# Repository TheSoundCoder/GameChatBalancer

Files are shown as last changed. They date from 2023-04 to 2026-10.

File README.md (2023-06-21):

# GameChatBalancer
GameChatBalancer is an **opensource hardware audio balancer** for Windows PCs. The functionality is inspired by the Chatmix / Gamevoice mix function of some available headsets.

GameChatBalancer lets you use an Arduino (or compatible) based knob or slider to **balance the volume of chat-software and games** so that you can **easily
tune the audio volume while playing** without any interruption by just turning a knob or moving a slider.

The project consists of two components. A small **systray application** for your PC and an Arduino based **cheap to build** hardware.

# Table of contents
- [Features](https://github.com/TheSoundCoder/GameChatBalancer#Features)
- [Build Hardware](https://github.com/TheSoundCoder/GameChatBalancer#build-hardware)
  - [Schematic](https://github.com/TheSoundCoder/GameChatBalancer#schematic)
  - [Material](https://github.com/TheSoundCoder/GameChatBalancer#material)
  - [Housing](https://github.com/TheSoundCoder/GameChatBalancer#housing)
- [Make your own GameChatBalancer](https://github.com/TheSoundCoder/GameChatBalancer#make-your-own-gamechatbalancer)
- [Licences](https://github.com/TheSoundCoder/GameChatBalancer#licences)
- [Roadmap](https://github.com/TheSoundCoder/GameChatBalancer#roadmap)
- [Special Thanks](https://github.com/TheSoundCoder/GameChatBalancer#special-thanks)
- [Help & Feedback](https://github.com/TheSoundCoder/GameChatBalancer/#help--feedback-wanted)

# Features
1. Hardware
   - Only sends data via the serial port if the chose volume level changed -> **no permanent datastream**
   - **Noise reduction** in case you are using cheap components - especially the potentiometer
     - Levels: Off, Low, Medium, High (default)
     - Adjustable at runtime via Systray Application

2. Systray Application
   - Easy configuration via GUI - Assign applications via **drag and drop**
   - Assign **multiple applications** to the "Game" and "Chat" category
   - **Auto-detect** the Arduino based hardware
   - The application detects when the hardware is removed and will automatically reconnect when plugged in again (**USB event based**)
   - User settings are stored automatically and restored during application startup
   - Invert the values received by the hardware in case your wiring is mixed up

See the application in action:

https://user-images.githubusercontent.com/130736237/235218694-252510ab-6273-4d05-bc87-e7d56919cefa.mp4

This is how it look like in the Windows Audio mixer:

https://user-images.githubusercontent.com/130736237/235218894-d49eed7c-69e4-4d56-9448-dae65230d700.mp4

# Build Hardware
Everything you need to build your own GameChatBalancer ist listed in the [Pricing indication](https://github.com/TheSoundCoder/AudioControl#pricing-indication).
- The potentiometer is connected to an analog pin of your Arduino (or compatible) board. It is powered from the board's 5V (or 3.3V for a Seeed board) output (see schematic)
  - GND = black
  - 5V / 3.3V = red
  - Signal = green
- The board is conected via an USB cable to the PC. **Make sure to check what kind of USB cable is needed for your board.**
- As listed in the Pricing indication I used a **Seeed Xiao SAMD21 Cortex M0+** instead of an Arduino. It comes cheap (5,60€), has a lot of analog connectors and a very small footprint (20mm x 17,5mm x 3,5mm) so that it fits into a small housing. Last but not least it has a USB-C connector.
 
## Schematic
In the schematic below, you can find two options:
1. *Left* is the setup with the *Seeed Xiao SAMD21 Cortex M0+*. **Ensure to connect the potentiometer to the 3.3V output** of the board as the 5V will probably kill the board's microcontroller.
2. *Right* is the setup with an *Arduino*.

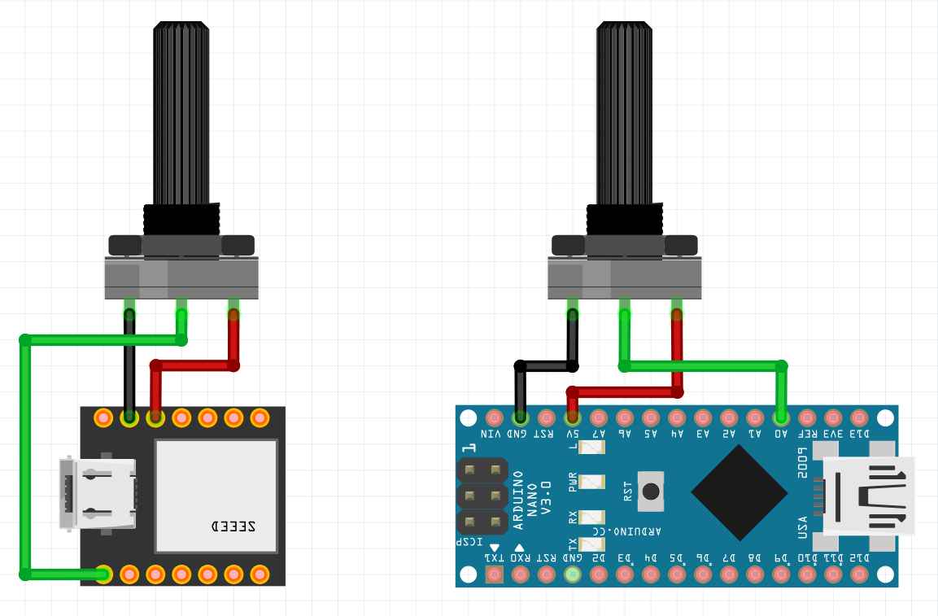
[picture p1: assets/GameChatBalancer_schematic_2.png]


## Material
**Please keep in mind that a cheap potentiometer can cause noise**, so that noise reduction needs to be switched on in the Systray application.
I use a ~ 3€ poti with a **low tolerance of +-5%** in my device and noise reduction switched off. Cheap potentiometers usually have a tolerance of +-20%.

**Important**: make sure to buy a **linear** potentiometer, not a logarithmic one! 

Item | Price (€)|Link
-----|------|-------
Microcontroller: Seeed Xiao SAMD21 Cortex M0+|5,60|https://www.berrybase.de/en/seeeduino-xiao-arduino-microcontroller-samd21-cortex-m0
Potentiometer Noname 10k (tolerance: +-20%)|0,45|https://www.berrybase.de/en/drehpotentiometer-10k-937-liegend-mono-6mm-loetoesen?c=164
*Optional:* Potentiometer Alpha RV16AF20KB10KM (tolerance: +-5%)|2,99|https://www.conrad.de/de/p/alpha-rv16af20kb10km-dreh-potentiometer-mono-200-mw-10-k-1-st-1694304.html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 
Knob|0,65|https://www.berrybase.de/en/drehknopf-fuer-geraendelte-6-0mm-achse-mit-anzeige-16x16mm-schwarz/grau?c=164
Copper wire isolated|1,50|https://www.berrybase.de/en/kupferschaltdraht-isoliert-oe0-5mm-10m
**Total**|**8,20 - 10,74**|

If you use the listed microcontroller you will additionally need a **USB-C cable**.

## Housing
You can use anything as a housing for your GameChatBalancer - even a matchbox if you do not have a 3D-Printer.

I decided to design and 3D-print one by myself. If you like the "design" you can download either the STL files or GCODE files [here](https://github.com/TheSoundCoder/AudioControl/tree/master/assets/3d-model).

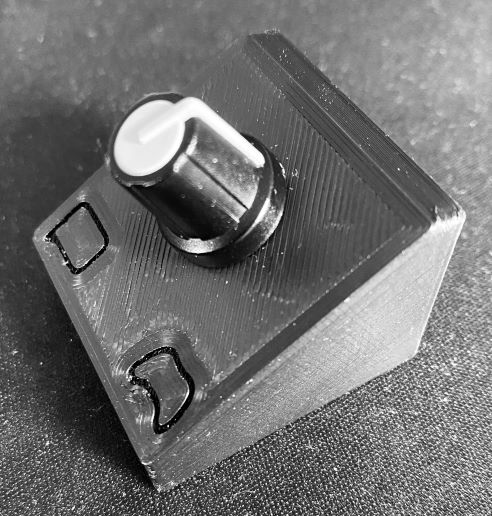
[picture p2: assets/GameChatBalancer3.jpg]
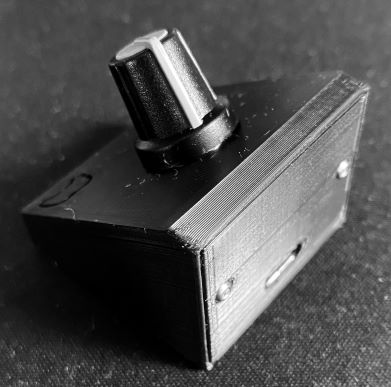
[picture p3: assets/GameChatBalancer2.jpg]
 

# Make your own GameChatBalancer

If you want to build your own GameChatBalancer or get details on how to handle the systray application. Please have a look at the dedicated [manual](https://github.com/TheSoundCoder/GameChatBalancer/blob/master/Manual.md).

# Licences
Icons used under [Creativecommons Attribution 4.0](https://creativecommons.org/licenses/by/4.0/legalcode) from https://icon-icons.com:
Designer | Iconpack | Icon Name | Image
---------|----------|---------|---------
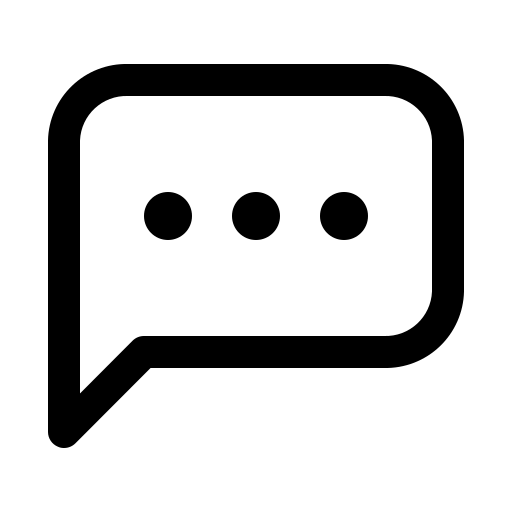
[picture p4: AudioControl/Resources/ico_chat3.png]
Perpixel | Mobile Basic Vol. 1 | conversation Icon | 
Iconicons | Icons - line | Game, controller icon | 
CoreUI | CoreUI Free | Equalizer Icon | 
Steve Shoger | Zondicons | Bug Icon | 
Yannick | General Icons | Refresh Icon | 

# Roadmap
Depending on my free time I would like to make the complete setup flexible so that additional potentiometers are supported. Those could be used to (e.g.):
- Control the master volume of your PC
- Assign single or multiple applications to a potentiometer

I am currently thinking of how the Systray UI and configuration of the Arduino can be done flexible so that no new sketch needs to be uploaded if the overall configuration changes.

# Special Thanks
I would like to thank **@sverrirs for his Gist AudioManager.cs** which accelerated the development and for sure saved me from some pain during the development. I used and modified AudioManager.cs to my needs so that GameChatBalancer is able to adjust the volume of more than one application by application name in one single call.

# Help & Feedback wanted
I created a first issue where help would be very welcome. Maybe it is not an easy one, but if somebody has a good idea or would like to contribute to it, this would be very welcome. This is my first (public) repo, so please be patient with me.

Feedback is also more than welcome. Please let me know if you (dis-) LIKE something or if you see issues in the code have good hints how to improve.

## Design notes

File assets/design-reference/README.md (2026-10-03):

# Design Reference Asset

Lege hier das bereitgestellte Referenzbild ab:

- `GameChatBalancer-Reference.jpeg`

Dieser Asset-Pfad wird in den Projekt-Instructions verwendet und dient als visuelle Leitlinie für die WPF-UI-Modernisierung.

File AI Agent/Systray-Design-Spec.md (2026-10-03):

# GameChatBalancer – Mini-Design-Spec Systray-Popup (WPF, Fluent)

## Ziel
Systray-Popup visuell an die neue WPF-Hauptoberfläche angleichen (Windows-11-/Fluent-inspiriert), mit zwei klaren Zuständen:
1. **Arduino verbunden** (Hardware-Steuerung aktiv)
2. **Arduino nicht verbunden** (Software-Steuerung aktiv)

Die Mockups sind Leitlinie, keine pixelgenaue Vorgabe. Funktionalität/Stabilität haben Vorrang.

---

## 1) Layout & Größe
- Popup als kompakte Card über der Taskleiste.
- Zielgröße (Startwert): ca. **360–400px Breite**, Höhe dynamisch nach Inhalt.
- Außenabstand: 8–12px zur Taskleistenkante.
- Innenabstand Card: 16px.
- Vertikaler Rhythmus: 8/12px zwischen Gruppen.

### Struktur (von oben nach unten)
1. **Header**
   - App-Icon + Titel "GameChatBalancer"
2. **Status-Card**
   - Dot + Statuszeile + optionale Geräteinfo
3. **Balance-Bereich**
   - Game/Chat Werte + Gradient-Track + Indikator
4. **Mode-spezifischer Block**
   - Connected: Noise Reduction + Invert
   - Disconnected: Software-Control-Hinweis + Hotkeys
5. **Actions-Liste**
   - Open App
   - Start with Windows (Toggle)
   - Exit

---

## 2) Farb- & Materialsystem
(auf Basis `AI Agent/UI-Design-Reference.md`)

- Background/Base: `#0A1326`
- Surface 1: `#10203A`
- Surface 2: `#132743`
- Border/Subtle: `#2A3D5A`
- Text Primary: `#F2F6FF`
- Text Secondary: `#AFC0D8`
- Accent Game: `#2B8CFF`
- Accent Chat: `#8A5CFF`
- Success (Connected): `#22C55E`
- Error (Disconnected): `#EF4444`

Material:
- Hauptpanel: Surface 2
- Eingelassene Bereiche/Rows: Surface 1
- Border 1px subtil
- Keine harten Glows, nur sanfte Kontraste

---

## 3) Typografie
- Font: Segoe UI Variable / Segoe UI
- Größen:
  - Titel: 30
  - Abschnittstitel: 16
  - Primärtext: 14
  - Sekundärtext/Meta: 12–13
- Gewicht:
  - Titel/Sektion: Semibold/Bold
  - Meta: Regular

---

## 4) Corner Radius, Spacing, Controls
- Große Card: 12px
- Kleine Unterkarten/Rows: 8–10px
- Toggle-Stil identisch zum WPF-Hauptfenster (`HardwareToggleStyle`)
- Dropdown-Stil für Noise Reduction an Hauptfenster angleichen
- Fokuszustände sichtbar, Hover klar, Disabled lesbar

---

## 5) Zustand A – Arduino verbunden
- Statuszeile:
  - Grüner Dot + „Arduino verbunden“
  - Unterzeile optional: Gerät + Firmware
- Hardware-Steuerung sichtbar:
  - Noise Reduction (Value + Auswahl)
  - Invert Control (Toggle)
- Software-Control-Hinweis **ausgeblendet**

## 6) Zustand B – Arduino nicht verbunden
- Statuszeile:
  - Roter Dot + „Kein Arduino verbunden“
  - Unterzeile: „Software-Steuerung aktiv“
- Hardware-Steuerung **ausgeblendet**:
  - Kein Noise Reduction Block
  - Kein Invert Toggle
- Software-Control-Info sichtbar:
  - Hinweistext zu 5%-Schritten
  - Hotkeys:
	- Ctrl + Shift + ← / →
	- Ctrl + Shift + ↓ (Center 50)

---

## 7) Interaktion
- Open App: öffnet Hauptfenster
- Start with Windows: synchron mit bestehender Autostart-Logik
- Exit: beendet App sauber
- Klick außerhalb Popup: schließt Popup (wie Kontext-ähnliches Flyout)

---

## 8) Accessibility & UX
- Tastaturfokus für alle aktiven Elemente
- Nicht nur Farbe als Statussignal (Text immer vorhanden)
- Kontrast min. AA-nah für Primärtexte
- Tooltips für Status/unklare Icons

---

## 9) Technische Leitplanken für Umsetzung
- Schrittweise umsetzen:
  1. Nur Popup-Layout + Styles
  2. State-Switch Connected/Disconnected
  3. Actions/Bindings
- Bestehende Services/Logik zuerst weiterverwenden, keine Big-Bang-Refactorings.
- Nach jedem Schritt: Build + kurzer Smoke-Test.

---

## 10) Abnahmekriterien (Systray-Phase)
- Popup folgt visuell der WPF-Designsprache.
- Connected/Disconnected unterscheiden sich klar und korrekt.
- Bei Disconnected sind Hardware-Controls vollständig ausgeblendet.
- Software-Control-Hotkeys sind im Popup sichtbar dokumentiert.
- Actions (Open App, Start with Windows, Exit) funktionieren wie bisher.
- Keine Regression bei Tray-Show/Hide/Exit.

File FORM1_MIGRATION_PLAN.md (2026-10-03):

# FORM1 Migration Plan

## Scope (Phase 1 only)
This document captures the current Form1 dependency graph and a safe migration path.  
No Form1 deletion is performed in this phase.

---

## 1) Current responsibilities of `Form1`

### Application host / lifecycle
- App startup host (`Program.Main` starts `new Form1()`)
- Subscribes global lifecycle events:
  - `Application.ApplicationExit`
  - `SystemEvents.SessionEnding`
- Owns startup sequencing (`Form1_Load`), including initialization order.
- Owns shutdown sequencing (`OnApplicationExit`, `PersistSettingsImmediate`, service stop/shutdown).

### Tray behavior
- Owns `NotifyIcon` and interaction entry points (`trayicon_MouseUp`).
- Creates/displays `SystrayPopupWindow` and positions it.
- Handles tray commands (`Show`/`Exit`) via `openToolStripMenuItem_Click` and `closeToolStripMenuItem_Click`.

### WPF window hosting/orchestration
- Creates `MainWindow` with many callbacks/providers.
- Keeps `MainWindow` and systray popup synchronized with runtime state.
- Intercepts WPF main-window close (`WpfMainWindow_Closing`) to hide instead of exit.

### Audio control orchestration
- Calls `IAudioBalanceService.ApplyBalance(...)`.
- Maintains current balance mirror in WinForms controls (`trackBar1`, labels) and propagates to WPF UI.
- Responds to incoming Arduino volume values via `controlVolume(...)`.

### Arduino/serial orchestration
- Uses `ISerialDeviceService` and reacts to `ConnectionStatusChanged`.
- Triggers startup handshake/value fetch (`GetVol`) and noise reduction command send.
- Applies noise reduction/invert settings and propagates to UI surfaces.

### Process/audio-session detection orchestration
- Uses `IAudioSessionService`.
- Subscribes to `AudioSessionsChanged` and refreshes assignment lists/snapshots.

### Settings and assignment persistence orchestration
- Reads/writes `ISettingsStore`.
- Maintains `GAME`/`CHAT` assignment strings and app path mapping.
- Persists state at runtime and on shutdown.

### Hotkeys (software control when Arduino disconnected)
- Registers/unregisters Win32 hotkeys in host window (`WndProc`).
- Applies step/snap/center logic and routes result through balance apply path.

### Debug/log sink and UI debug state
- Maintains in-memory debug log list.
- Routes logs into legacy WinForms textbox and WPF debug page callbacks.

### Legacy WinForms UI state bridge (technical debt)
- Exposes/uses WinForms control state as runtime state source:
  - COM dropdown
  - invert checkbox
  - volume labels/trackbar
  - listboxes for assignment
- This state is currently used by serial/audio paths indirectly.

---

## 2) All known consumers/dependencies on `Form1`

## Direct references
- `AudioControl/Program.cs`
  - `WinFormsApplication.Run(new Form1())`
- `AudioControl/SerialDeviceService.cs`
  - Constructor signature `SerialDeviceService(Form1 form)`
  - Calls `USBandCOM.HandOverForm(form)`
- `AudioControl/AudioSessionService.cs`
  - Constructor signature `AudioSessionService(Form1 form)`
  - Calls `AudioManager.AudioManager.HandOverForm(form)`
- `AudioControl/USBandCOM.cs`
  - Static field `MainForm` of type `AudioControl.Form1`
  - Extensive calls to `MainForm.*` for logging/UI-thread marshaling/state updates
- `AudioControl/AudioManager.cs`
  - Static field `MainForm` of type `AudioControl.Form1`
  - Uses `MainForm.Debug` + `MainForm.SendToLog(...)`

## Indirect dependencies
- WPF UIs depend on Form1-owned callback graph:
  - `GameChatBalancer.Wpf/MainWindow.xaml.cs` (callbacks provided by Form1)
  - `GameChatBalancer.Wpf/SystrayPopupWindow.xaml.cs` (callbacks provided by Form1)
- USB watcher service (`UsbWatcherService`) and serial layer depend on `USBandCOM`, which currently depends on Form1.

## Startup/lifecycle dependency
- Entire application runtime currently requires Form1 as process host window/message pump anchor.

---

## 3) Responsibility -> proposed destination

| Responsibility in Form1 | Proposed destination |
|---|---|
| App startup orchestration | New `AppHost` / `ApplicationLifecycleService` (non-UI) |
| Tray icon + menu/popup wiring | New `ITrayHostService` (WinForms `NotifyIcon` can remain internal implementation detail) |
| MainWindow creation/show/hide policy | New `IWindowCoordinator` / `IUiCoordinator` |
| Runtime app state (connected, balance, noise, invert, assignments) | New `IAppStateStore` + event stream |
| Software-control hotkeys | New `ISoftwareControlHotkeyService` (host-level, independent of MainWindow) |
| Serial value intake + command dispatch coordination | New `IArduinoController` (uses `ISerialDeviceService`) |
| Balance application orchestration | Keep `IAudioBalanceService`, add thin `IBalanceController` for orchestration/state events |
| Audio-session refresh/reassignment triggering | New `IAssignmentRefreshService` (uses `IAudioSessionService`) |
| Debug logging fan-out | New `IAppLogger` / `IDebugLogStore` abstraction |
| Settings persistence flow | Keep `ISettingsStore`, move shutdown save into lifecycle service |

Guiding rule: no `Form1` reference in core/services; UI consumes abstractions/events.

---

## 4) Required interfaces/services (incremental)

## Reuse existing
- `ISerialDeviceService`
- `IAudioSessionService`
- `IAudioBalanceService`
- `IUsbWatcherService`
- `ISettingsStore`
- `IAutoStartService`

## Introduce (small focused components)
- `IAppStateStore` (current state + change events)
- `IArduinoController` (serial connect/disconnect, incoming value event, NR ack event, send commands)
- `IBalanceController` (apply balance, emit balance changed)
- `ISoftwareControlHotkeyService` (register/unregister, hotkey events)
- `ITrayHostService` (notify icon lifecycle, show/hide popup commands)
- `IUiCoordinator` (open main window, sync UI state, close policy)
- `IAppLifecycleService` (startup/shutdown sequencing and disposal)
- `IDebugLogStore` (log sink + observable log entries)

No “Form1Service” aggregation class.

---

## 5) Required event flows (event-driven, no polling)

## Serial/Arduino flow
1. `IArduinoController.ConnectionStatusChanged`
2. `IAppStateStore` updates connected/port state
3. Subscribers update:
   - Tray popup state
   - MainWindow state
   - Hotkey service registration policy

## Arduino value flow
1. `IArduinoController.ValueReceived(float)`
2. `IBalanceController.ApplyInput(value, invert)`
3. `IBalanceController.BalanceChanged` (display/game/chat)
4. Subscribers:
   - Audio controller/session volume application
   - MainWindow balance UI
   - Systray popup balance UI

## Noise reduction flow
1. UI command -> `IArduinoController.SetNoiseReduction(level)`
2. state enters applying
3. NR confirmation event from serial -> state confirmed
4. timeout/error event -> state error

## Audio session change flow
1. `IAudioSessionService.AudioSessionsChanged`
2. assignment refresh service recomputes available apps
3. `IAppStateStore.AvailableAppsChanged`
4. MainWindow refreshes assignment lists

## Lifecycle flow
- Startup: initialize services in host service order (settings -> serial/usb watcher -> session monitor -> tray)
- Shutdown: reverse order with deterministic dispose/unsubscribe.

---

## 6) Event handlers currently wired through Form1

## Framework/lifecycle
- `Application.ApplicationExit += OnApplicationExit`
- `SystemEvents.SessionEnding += OnSessionEnding`

## Service events
- `serialDeviceService.ConnectionStatusChanged += SerialDeviceService_ConnectionStatusChanged`
- `audioSessionService.AudioSessionsChanged += AudioSessionService_AudioSessionsChanged`

## WinForms UI handlers (Designer)
- Tray: `trayicon_MouseUp`
- Context menu / commands: `openToolStripMenuItem_Click`, `closeToolStripMenuItem_Click`, `Settings_Opening`
- Controls: `ddl_ComPort_SelectedIndexChanged`, `ddlNoiseReduction_SelectedIndexChanged`, `cb_Debug_CheckedChanged`, `cb_invert_CheckedChanged`, drag/drop handlers, etc.

## Win32 message hook
- `WndProc` for software hotkeys.

---

## 7) Static/global Form1 access identified

- `USBandCOM.MainForm` static field (`AudioControl.Form1`)
- `USBandCOM.HandOverForm(Form1 f)`
- `AudioManager.MainForm` static field (`AudioControl.Form1`)
- `AudioManager.HandOverForm(Form1 f)`

These are the primary blockers for Form1 deletion.

---

## 8) WinForms-specific access caused by Form1 coupling

Core/runtime paths currently read/write WinForms controls indirectly via Form1:
- COM state via `SystrayCom`, `Connected`, `Fill_ddl_ComPort`, `Initialized`
- Balance state via `trackBar1`, `lbl_game_vol`, `lbl_chat_vol`, `lbl_absoluteval`
- Invert state via `cb_invert`
- Debug output via `textBox1`
- Assignment management through listbox manipulation methods

This must move to neutral state/services before Form1 removal.

---

## 9) Initialization/shutdown responsibilities currently in Form1

## Constructor
- Creates/default-injects service instances
- Wires serial connection event
- syncs assignment-path store from persisted settings

## Load
- Initializes assignment/process lists
- Normalizes defaults (`NoiseReduction`, `ComPort`)
- Starts USB watcher
- Opens serial port and requests initial value
- Registers startup hotkeys according to connection state
- Hides legacy form and shows tray
- Initializes systray popup state
- Starts audio session monitoring

## Runtime close/hide
- MainWindow closing intercepted (hide-to-tray behavior)

## Exit/session ending
- Unregister hotkeys
- Stop session monitoring and unsubscribe
- Persist settings
- Stop USB watcher
- Shutdown serial service
- Unsubscribe `SystemEvents.SessionEnding`

---

## 10) What would break if Form1 were removed now

- Application startup (entry point instantiates Form1)
- Serial/USB pipeline (`SerialDeviceService` + `USBandCOM`) due to hard `Form1` dependency
- Audio session service logging bridge (`AudioSessionService` -> `AudioManager.HandOverForm`)
- Tray icon and popup lifecycle (currently hosted by Form1)
- Software-control hotkeys (currently in Form1 `WndProc`)
- Current state synchronization between serial/audio/tray/WPF callbacks
- Shutdown/disposal sequencing currently centralized in Form1

---

## Migration order (recommended, incremental)

1. Introduce `IDebugLogStore` and remove `AudioManager`/`USBandCOM` direct `Form1` logging dependency.
2. Refactor `USBandCOM` to depend on neutral callbacks/events/state interface (no `Form1` type).
3. Refactor `SerialDeviceService` constructor to remove `Form1` parameter.
4. Refactor `AudioSessionService` constructor to remove `Form1` parameter.
5. Introduce `IAppStateStore` for connected/port/balance/noise/invert/assignments runtime state.
6. Extract software hotkeys into `ISoftwareControlHotkeyService` (host-level, not MainWindow-bound).
7. Extract tray host/popup control into `ITrayHostService`.
8. Extract WPF window coordination (`IUiCoordinator`) from Form1.
9. Move startup/shutdown orchestration into `IAppLifecycleService`.
10. Update `Program.Main` to start new host service (not Form1).
11. Search and remove remaining `Form1` references.
12. Delete `Form1.cs`, `Form1.Designer.cs`, `Form1.resx` and obsolete wiring.
13. Final build/tests + runtime validation checklist.

---

## Potential risks

- Hidden assumptions on WinForms control values as source-of-truth.
- Event-threading regressions during serial callbacks and UI dispatch transitions.
- Hotkey registration conflicts if ownership changes incorrectly.
- Resource leaks (serial port, watcher, session monitor, event subscriptions) if lifecycle extraction order is wrong.
- Tray behavior regressions if host window/message loop responsibilities are moved without equivalent handling.

---

## Final deletion checklist

- [ ] `Program.Main` no longer creates `new Form1()`.
- [ ] `SerialDeviceService` has no `Form1` constructor dependency.
- [ ] `AudioSessionService` has no `Form1` constructor dependency.
- [ ] `USBandCOM` contains no `Form1` type/member usage.
- [ ] `AudioManager` contains no `Form1` type/member usage.
- [ ] No `Form1`/`form1` references in solution-wide search (except migration docs/changelog).
- [ ] Tray popup and main window state sync driven by services/events, not Form1 callbacks.
- [ ] Startup without opening MainWindow still initializes core/tray/hotkeys correctly.
- [ ] Shutdown disposes serial/USB/audio/hotkeys cleanly and unsubscribes events.
- [ ] Remove `Form1.cs`, `Form1.Designer.cs`, `Form1.resx` from project.
- [ ] Full solution build passes.
- [ ] Existing tests pass.
- [ ] Manual smoke checks pass: startup, tray, reconnect, balance, hotkeys, settings persistence, exit/restart.

---

## Progress update (Phase 2 - in progress)

Completed refactorings:
- Introduced `IDiagnosticsSink` (generic diagnostics/log contract).
- Introduced `ISerialHostBridge` (small host callback/dispatch contract for serial layer).
- `AudioManager` no longer stores a static `Form1` reference for diagnostics:
  - replaced with `IDiagnosticsSink` via `HandOverDiagnosticsSink(...)`.
- `AudioSessionService` constructor migrated from `Form1` to `IDiagnosticsSink`.
- `USBandCOM` migrated from static `Form1 MainForm` to `ISerialHostBridge`:
  - logging, dispatching, connected state, COM refresh, NR confirm/send, and volume callback now go through bridge methods.
- `SerialDeviceService` constructor migrated from `Form1` to `ISerialHostBridge`.
- `Form1` now implements `ISerialHostBridge` (and therefore `IDiagnosticsSink`) as an adapter during transition.

Resulting dependency improvements:
- Removed direct `Form1` type dependency from:
  - `AudioControl/AudioManager.cs`
  - `AudioControl/AudioSessionService.cs`
  - `AudioControl/USBandCOM.cs`
  - `AudioControl/SerialDeviceService.cs`

Validation:
- Solution build successful after migration.

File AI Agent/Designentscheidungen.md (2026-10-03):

# GameChatBalancer – Designentscheidungen (ADR-Log)

> Dieses Dokument ist das zentrale Entscheidungsprotokoll.
> Jede relevante Architektur-/Technikentscheidung wird hier mit Kontext, Alternativen und Konsequenzen festgehalten.

## Verwendung
- Neue Entscheidung als neuer Abschnitt `ADR-XXXX`
- Status pflegen: `Proposed`, `Accepted`, `Superseded`, `Deprecated`
- Bei Änderungen nie alte Entscheidung löschen, sondern durch neue ADR ablösen

---

## ADR-0001 – Migrationsstrategie
- **Status:** Accepted
- **Datum:** 2026-09-25

### Kontext
Die bestehende App ist eine .NET-7-WinForms-Systray-App mit Hardware-Serial-Kommunikation und CoreAudio-Interop. Ziel ist eine native Windows-11-Anwendung ohne Funktionsverlust.

### Entscheidung
Migration **inkrementell** statt Big-Bang:
1. Frühzeitig auf aktuelles .NET migrieren
2. Architektur entkoppeln (Core/Application/Infrastructure)
3. Neue UI auf entkoppelter Schicht aufbauen

### Alternativen
- Direkter Komplettumstieg inkl. gleichzeitiger UI-/TFM-/Architektur-Neubau

### Konsequenzen
- Niedrigeres Risiko
- Bessere Testbarkeit
- Kürzere Feedbackzyklen

---

## ADR-0002 – Frühphase: .NET-Migration
- **Status:** Accepted
- **Datum:** 2026-09-25

### Kontext
Der aktuelle Stand ist `net7.0-windows`; langfristige Wartbarkeit und moderne Plattformfeatures erfordern eine aktuelle .NET-Version.

### Entscheidung
Die Migration auf ein **aktuelles .NET (LTS bevorzugt)** erfolgt in einer frühen Projektphase (vor dem UI-Neubau).

### Alternativen
- TFM-Upgrade erst nach UI-Migration

### Konsequenzen
- Frühzeitige Sichtbarkeit von Kompatibilitätsproblemen
- Vermeidet doppelte Migration (erst UI, dann TFM)

---

## ADR-0003 – Ziel-UI in Phase 1
- **Status:** Accepted
- **Datum:** 2026-09-25

### Kontext
Es stehen zwei UI-Ziele im Raum: WinUI 3 oder WPF (Fluent).

### Entscheidung
**Phase-1-Ziel: WPF mit modernem Fluent UI** für schnelle, risikoarme Funktionsparität.
**WinUI 3 wird explizit auf einen späteren Zeitpunkt verschoben** und erst nach stabiler WPF-Produktivphase erneut bewertet.

### Alternativen
- Sofortiger Wechsel auf WinUI 3 / Windows App SDK

### Konsequenzen
- Bessere Beherrschbarkeit von Tray-/Interop-Szenarien
- Schnellere Erreichung der Funktionsparität zur bestehenden WinForms-App
- WinUI 3 bleibt als optionaler Folgepfad möglich

---

## ADR-0004 – Hardware-Protokoll-Stabilität
- **Status:** Accepted
- **Datum:** 2026-09-25

### Kontext
Bestehende Geräte im Feld erwarten das bestehende Protokoll.

### Entscheidung
Das Protokoll (`syn`, `ack`, `get`, `NR=0..3`, Werte 0..100) bleibt kompatibel.

### Alternativen
- Neues Protokoll mit Breaking Changes

### Konsequenzen
- Abwärtskompatibilität bleibt erhalten
- Migration kann ohne Firmware-Zwang starten

---

## ADR-0005 – Zielversion für frühe .NET-Migration
- **Status:** Accepted
- **Datum:** 2026-09-25

### Kontext
Die Anwendung läuft aktuell auf `net7.0-windows`. Für die frühe Plattformmigration wurde eine konkrete Zielversion benötigt.

### Entscheidung
Die frühe Plattformmigration erfolgt auf **`net10.0-windows`**.

### Alternativen
- `net8.0-windows` als konservativerer Zwischenstand

### Konsequenzen
- Einheitliches Ziel für alle Folgeaufgaben (`01.02` ff.)
- Build-/Paketprüfung wird direkt gegen .NET 10 durchgeführt

---

## ADR-0006 – Funktionsschutz vor Visual Redesign
- **Status:** Accepted
- **Datum:** 2026-09-26

### Kontext
Die Modernisierung enthält starke UI/UX-Ziele, darf aber bestehende Kernfunktionen nicht gefährden.

### Entscheidung
Priorisierung wird verbindlich festgelegt: **Funktionalität → Stabilität → Architektur → UX → Visual Design → Cleanup**.

### Alternativen
- Design-first-Ansatz mit späterer Funktionsangleichung

### Konsequenzen
- Geringeres Regressionsrisiko
- Klarer Entscheidungsrahmen bei Zielkonflikten

---

## ADR-0007 – Keine stillen Funktionsänderungen
- **Status:** Accepted
- **Datum:** 2026-09-26

### Kontext
Bei Refactoring/Migration entstehen oft opportunistische „Nebenverbesserungen“, die Verhalten ändern können.

### Entscheidung
Funktionsänderungen ohne explizite Freigabe sind untersagt. Verbesserungen werden als **Potential Improvement** dokumentiert (Reason/Risk/Recommendation), aber nicht automatisch umgesetzt.

### Alternativen
- Direkte Umsetzung opportunistischer Verbesserungen während der Migration

### Konsequenzen
- Vorhersehbares Migrationsverhalten
- Höhere Nachvollziehbarkeit im Projektverlauf

---

## ADR-0008 – Verbindliche Phasen-Gates
- **Status:** Accepted
- **Datum:** 2026-09-26

### Kontext
Die Migration muss kontrolliert in kleinen Schritten erfolgen.

### Entscheidung
Nach jeder Phase sind verbindlich: Build, Fehlerbehebung, Warning-Prüfung, Regression gegen Abnahmecheckliste, Fortschrittsdokumentation.

### Alternativen
- Größere Umbaupakete mit später Sammelvalidierung

### Konsequenzen
- Frühes Erkennen von Problemen
- Kleinere, besser isolierte Änderungsblöcke

---

## ADR-0009 – Event-Driven Architektur bleibt verbindlich
- **Status:** Accepted
- **Datum:** 2026-09-26

### Kontext
Die Anwendung verarbeitet Hardware- und Audiozustände bereits eventbasiert. Polling-Ansätze würden unnötige Last und Komplexität einführen.

### Entscheidung
GameChatBalancer bleibt strikt event-driven. Für Arduino/Balancer/UI/Overlay werden keine kontinuierlichen Polling-Schleifen oder periodischen Timer eingeführt, sofern Ereignisse verfügbar sind.

### Erlaubte Ausnahmen
Timer nur für inhärent timerbasierte Fälle (Overlay-AutoHide, Animationstiming, Debouncing).

### Konsequenzen
- Niedrigerer Laufzeit-Overhead
- Klarere Zustandsflüsse über Events
- Bessere Skalierbarkeit für WPF/ViewModel-basierte Weiterentwicklung

---

## ADR-Template (für neue Entscheidungen)

```md
## ADR-XXXX – Titel
- Status: Proposed|Accepted|Superseded|Deprecated
- Datum: YYYY-MM-DD

### Kontext
...

### Entscheidung
...

### Alternativen
...

### Konsequenzen
...

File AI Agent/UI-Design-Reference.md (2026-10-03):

# GameChatBalancer – UI Design Reference (Windows 11 / Fluent)

## Zweck
Diese Datei ist die verbindliche Design-Referenz für die WPF-Modernisierung.
Sie beschreibt die visuelle Sprache und UX-Prinzipien auf Basis des bereitgestellten Referenz-Screenshots.

## Wichtige Regel
Das Referenzbild ist **keine pixelgenaue Spezifikation**.
Es dient als visuelle Richtung. Funktionalität und Stabilität bleiben priorisiert.

## Referenzbild
- Erwarteter Pfad im Repository: `assets/design-reference/GameChatBalancer-Reference.jpeg`
- Hinweis: Falls die Datei fehlt, bitte das bereitgestellte Referenzbild dort ablegen.

---

## Verbindliche Designprinzipien
- Windows-11-/Fluent-inspirierte Oberfläche
- Modernes, dunkles Desktop-UI mit klarer Hierarchie
- Tiefes Blau/Navy als Grundstimmung
- Subtile Layer/Transparenz, keine übertriebenen Effekte
- Runde Ecken, saubere Karten/Paneele
- Großzügige Abstände und moderne Typografie
- Akzentfarben: **Blau (Game)**, **Lila (Chat)**
- Moderne Sidebar-Navigation
- Zentrales großes Audio-Balance-Control
- Game-/Chat-Listen, Hardware-Status, Quick Actions, System-Audio
- Theme-Support: Dark/Light/System
- Display-Sprache der Applikation ist verbindlich **Englisch** (UI-Texte, Labels, States, Tooltips)

## Verbote
- Kein 1:1-Nachbau des Screenshots
- Kein „Gaming RGB“-Look
- Keine unnötigen visuellen Effekte
- Keine Funktionseinbußen durch Visual-Refactoring

---

## Kurzspezifikation vor UI-Implementierung

### 1) Farbpalette (Startwerte)
- `Background/Base`: `#0A1326`
- `Surface 1`: `#10203A`
- `Surface 2`: `#132743`
- `Border/Subtle`: `#2A3D5A`
- `Text Primary`: `#F2F6FF`
- `Text Secondary`: `#AFC0D8`
- `Accent Game`: `#2B8CFF`
- `Accent Chat`: `#8A5CFF`
- `Success`: `#22C55E`
- `Warning`: `#F59E0B`
- `Error`: `#EF4444`

### 2) Typografie
- Primär: Segoe UI Variable / Segoe UI
- Größenraster: 12 / 14 / 16 / 20 / 28
- Gewichte: Regular, Semibold, Bold

### 3) Spacing-System
- Basis: 4px
- Nutzwerte: 4 / 8 / 12 / 16 / 24 / 32
- Karten-Innenabstand: 16–24px

### 4) Corner Radius
- Kleine Controls: 8px
- Cards/Panel: 12px
- Große Container: 16px

### 5) Control-Styles
- Klare Focus-Ringe
- Hover/Pressed/Disabled eindeutig
- Hoher Kontrast bei Text und Interaktion

### 6) Card-Styles
- Dunkle Layer-Flächen
- Subtile Border
- Sehr leichte Schattierung, keine harte Glow-Optik

### 7) Navigation
- Linke Sidebar mit klaren Sektionen
- Aktiver Eintrag deutlich markiert
- Home, Game, Chat, Settings, About

### 8) Icon-Style
- Fluent-/Windows-Style Icons
- Vektor/SVG bevorzugt
- Keine Emoji-Icons

### 9) Zustände
- Hover: leichte Aufhellung/Border-Akzent
- Pressed: dunkler, klare Rückmeldung
- Disabled: reduzierter Kontrast, aber lesbar

### 10) Light Theme (Äquivalent)
- Heller Hintergrund + dunkler Text
- Akzentfarben bleiben semantisch (Game=Blau, Chat=Lila)
- Gleiche visuelle Hierarchie wie Dark Theme

### 11) Layout-Struktur
- Links: Navigation
- Mitte: Header + Audio-Balance + App-Listen
- Rechts: Hardware-Status, Schnellaktionen, System-Audio
- Responsiv für 1280/1920/2560 + 125%/150% DPI

---

## Umsetzungsregeln
1. Bestehende Funktionalität zuerst verstehen und erhalten.
2. Funktionen in die neue Designsprache übertragen, nicht ersetzen.
3. UI muss auf unterschiedliche Fenstergrößen und DPI reagieren.
4. Accessibility mitdenken (Tastatur, Fokus, Kontrast, Tooltips, nicht nur Farbe).
5. Vor jeder größeren UI-Phase: Build + Smoke/Regression prüfen.

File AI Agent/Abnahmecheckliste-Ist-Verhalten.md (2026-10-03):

# GameChatBalancer – Abnahmecheckliste (Ist-Verhalten / Regression)

> Zweck: Referenz für alle folgenden Migrationen (.NET-Upgrade, Entkopplung, WPF).
> 
> Ergebnis gilt als „bestanden“, wenn das beobachtete Verhalten der aktuellen WinForms-Version entspricht.

## Testumgebung
- Windows 11
- Aktuelle WinForms-Build der App
- Angeschlossenes Arduino/kompatibles Gerät mit bestehendem Protokoll (`syn/ack/get/NR`)
- Mindestens eine Chat-App (z. B. Discord) und eine Game-/Audio-App aktiv

## A. Start- und Tray-Verhalten

### A1 – Start im Tray
- [ ] App starten
- [ ] Prüfen: Fenster startet minimiert/versteckt
- [ ] Prüfen: Tray-Icon sichtbar

**Bestanden, wenn:** App primär im Tray lebt und nicht als normales Vordergrundfenster startet.

### A2 – Tray-Menü/Status
- [ ] Rechtsklick auf Tray-Icon
- [ ] Prüfen: COM-Statuszeile sichtbar
- [ ] Prüfen: letzte empfangene Volume-Zahl sichtbar
- [ ] Prüfen: Menüeinträge „Show“ und „Exit“ vorhanden

**Bestanden, wenn:** alle Status-/Bedienelemente im Kontextmenü vorhanden sind.

### A3 – Show/Hide/Exit
- [ ] „Show“ öffnet Settings-Fenster
- [ ] Fenster minimieren ⇒ Fenster versteckt sich wieder, Tray bleibt aktiv
- [ ] „Exit“ beendet App vollständig

**Bestanden, wenn:** Lifecycle exakt wie bisher funktioniert.

---

## B. COM-Port & Auto-Detect

### B1 – COM-Portliste
- [ ] Settings öffnen
- [ ] COM-Dropdown enthält „Auto“
- [ ] Verfügbare COM-Ports werden gelistet

### B2 – Auto-Detect + Handshake
- [ ] COM auf „Auto“ setzen
- [ ] App (neu) verbinden lassen
- [ ] Prüfen: Verbindung wird aufgebaut (Connected-Status)

**Bestanden, wenn:** Gerät über Handshake (`syn/ack`) erkannt und verbunden wird.

### B3 – Manuelle COM-Auswahl
- [ ] Konkreten COM-Port wählen
- [ ] Prüfen: Reconnect erfolgt sauber
- [ ] Prüfen: Status im UI/Tray aktualisiert

**Bestanden, wenn:** Portwechsel ohne Neustart stabil funktioniert.

---

## C. USB-Reconnect

### C1 – USB trennen
- [ ] Gerät im laufenden Betrieb abziehen
- [ ] Prüfen: Verbindung als getrennt markiert

### C2 – USB wieder verbinden
- [ ] Gerät wieder einstecken
- [ ] Prüfen: automatische Wiederverbindung ohne App-Neustart

**Bestanden, wenn:** eventbasierte Erkennung + Reconnect funktionieren.

---

## D. Hardware-Protokoll / Noise Reduction

### D1 – Initialwert abrufen
- [ ] Nach erfolgreicher Verbindung prüfen, ob Wertabruf erfolgt (`get`-Flow)
- [ ] UI zeigt plausiblen Wert (0..100)

### D2 – Noise Reduction setzen
- [ ] NR-Level ändern (Off/Low/Medium/High)
- [ ] Prüfen: Hardware bestätigt NR (Checkbox/Bestätigung)

**Bestanden, wenn:** NR-Kommandos zuverlässig gesendet und bestätigt werden.

---

## E. Audio-Session-Erkennung & Assignment

### E1 – Prozessliste aktualisieren
- [ ] Audio-App starten
- [ ] Refresh in App auslösen
- [ ] Prüfen: Prozess erscheint in „Available programs“

### E2 – Drag&Drop-Zuordnung
- [ ] Prozess nach CHAT ziehen
- [ ] Prozess nach GAME ziehen
- [ ] Prüfen: Einträge erscheinen korrekt in den Ziel-Listen

**Bestanden, wenn:** Zuordnung zuverlässig per Drag&Drop klappt.

---

## F. Mix-Logik (Kernfunktion)

### F1 – Grenzwerte
- [ ] Eingehender Wert < 50 ⇒ GAME wird abgesenkt, CHAT bleibt 100
- [ ] Eingehender Wert = 50 ⇒ beide 100
- [ ] Eingehender Wert > 50 ⇒ CHAT wird abgesenkt, GAME bleibt 100

### F2 – Invert
- [ ] „Invert“ aktivieren
- [ ] Prüfen: Richtung der Regelung ist logisch invertiert

**Bestanden, wenn:** Mix-Verhalten der bisherigen Logik entspricht.

---

## G. Persistenz

### G1 – Einstellungen speichern
- [ ] GAME/CHAT-Zuordnung ändern
- [ ] COM-Port/NR/Invert ändern
- [ ] App beenden und neu starten

### G2 – Wiederherstellung
- [ ] Prüfen: alle geänderten Werte sind nach Neustart vorhanden

**Bestanden, wenn:** User-Settings konsistent gespeichert und geladen werden.

---

## H. Debug/Diagnose (optional, aber empfohlen)

### H1 – Debug aktivieren
- [ ] Debug-Checkbox setzen
- [ ] Prüfen: erwartete Logeinträge erscheinen

**Bestanden, wenn:** Diagnoseinformationen reproduzierbar sichtbar sind.

---

## Abnahmeprotokoll

| Datum | Build/Commit | Ergebnis | Bemerkungen |
|---|---|---|---|
| YYYY-MM-DD |  |  |  |

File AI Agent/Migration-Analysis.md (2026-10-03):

# GameChatBalancer – Architektur- und Migrationsanalyse

## Scope
- Repository vollständig analysiert (Code + Dokumentation)
- Keine Codeänderungen vorgenommen
- Ziel: UI-Migration zu nativer Windows-11-Erfahrung bei Erhalt der bestehenden Hardware-/Protokoll-Funktionalität

---

## 1) Architekturüberblick (Ist-Zustand)

### Solution/Projekte
- **Solution:** `AudioControl.sln`
- **Projekt:** `AudioControl/AudioControl.csproj` (Single-Project-Desktop-App)

### Anwendungstyp
- **Desktop-App mit Windows Forms** (Systray-zentriert)
- Einstiegspunkt: `Program.cs` → `Application.Run(new Form1())`

### Schichten (implizit)
1. **UI-Schicht (WinForms):** `Form1.cs` + `Form1.Designer.cs`
2. **Hardware/Serial-Schicht:** `USBandCOM.cs`
3. **Windows Audio Integration:** `AudioManager.cs` (CoreAudio COM Interop)
4. **Konfiguration:** `Properties.Settings` / `App.config`

### Laufzeit-/Lifecycle-Modell
- Startet minimiert und lebt primär im **System Tray**
- GUI wird über Tray-Menü „Show“ geöffnet
- Bei Minimize wird Form versteckt (`Hide`) und Tray bleibt aktiv
- Beim Exit:
  - User-Settings speichern (`GAME`, `CHAT`, `ComPort`, `NoiseReduction`, `Invert`)
  - COM-Port schließen

---

## 2) Aktuelle UI-Technologie

- **Windows Forms** (`UseWindowsForms=true`)
- Klassisches Designer-basiertes UI
- Drag&Drop zwischen ListBoxen für App-Zuordnung
- `NotifyIcon` + `ContextMenuStrip` für Tray-Bedienung

---

## 3) .NET-Version

- `TargetFramework`: **`net7.0-windows`**
- `Nullable`: aktiviert
- `ImplicitUsings`: aktiviert

Hinweis: .NET 7 ist außerhalb regulärem Supportfenster. Für Windows-11-Zielbild ist ein Upgrade auf aktuelles LTS sinnvoll (z. B. .NET 8/10 je nach Zielzeitpunkt).

---

## 4) System-Tray-Implementierung

- WinForms `NotifyIcon` (`trayicon`) mit Kontextmenü
- Menü enthält u. a.:
  - COM-Status (`systrayCom`)
  - letzter Wert (`systrayVolume`)
  - Show/Exit
- Startzustand minimiert, Taskbar versteckt (`ShowInTaskbar=false`)

---

## 5) Arduino-/Serial-Kommunikation

### Transport
- `System.IO.Ports.SerialPort`
- Baudrate: **115200**
- Event-basiertes Lesen über `DataReceived`

### Auto-Detect/Handshake
- Bei `ComPort=Auto` werden verfügbare Ports iteriert
- Handshake:
  - App sendet: `syn`
  - Erwartete Antwort: enthält `ack`

### Laufzeitprotokoll (aus Code + Doku)
- App → Device:
  - `get` (aktuellen Wert anfordern)
  - `NR=0..3` (Noise Reduction setzen)
- Device → App:
  - numerische Werte `0..100` (Volume-Mix-Position)
  - Bestätigung `NR=`/NR-Response

### Robustheit
- USB-Watcher via WMI (`ManagementEventWatcher` auf `Win32_USBHub`)
- Bei Connect/Disconnect wird reconnect/init ausgelöst

---

## 6) Windows-Audio-Integration

- Eigene CoreAudio-COM-Interop in `AudioManager.cs`
- Session-Enumeration über `IAudioSessionManager2`
- Prozess-basierte Volume-Steuerung per Prozessname
- Logik:
  - Wert < 50: GAME runter (0..100 skaliert), CHAT 100
  - Wert > 50: CHAT runter, GAME 100
  - Wert = 50: beide 100
- Mehrere Apps je Kategorie via CSV-Listen (`GAME`, `CHAT`)

---

## 7) Konfigurationspersistenz

- `Properties.Settings` (User Scope)
- Persistierte Schlüssel:
  - `GAME`
  - `CHAT`
  - `ComPort`
  - `NoiseReduction`
  - `Invert`
- Speicherung bei Exit und bei bestimmten UI-Änderungen (z. B. COM-Auswahl)

---

## 8) Application Detection / Assignment

- Erkennung aktiver Audio-Apps über CoreAudio Session Enumeration
- Anzeige in `lb_AudioProcesses`
- Zuordnung per Drag&Drop in `lb_GAME` / `lb_CHAT`
- Speicherung als comma-separated Strings

---

## 9) Abhängigkeiten

### NuGet
- `System.IO.Ports` 7.0.0
- `System.Management` 7.0.1

### Plattform-/API-Abhängigkeiten
- Win32/CoreAudio COM
- WMI-Events (USB Detection)
- Serial Port
- Windows-spezifischer Desktop-Stack

---

## 10) Bewertung der Ziel-UI-Optionen

## Option 1: WinUI 3 / Windows App SDK

### Vorteile
- Modernste native Windows-11 UI
- Fluent Design out-of-the-box
- Gute langfristige UI-Ausrichtung für Windows

### Risiken / Aufwand
1. **System Tray nicht nativ first-class** in WinUI 3
   - Tray benötigt Win32-Interop/zusätzliche Komponenten
2. **Drag&Drop- und Desktop-Verhaltensmigration** erfordert UI-Neubau
3. **Lifecycle (minimized-to-tray)** muss explizit neu implementiert werden
4. **Mehr Moving Parts** (WinUI Windowing + Interop + ggf. Packaging/Unpackaged-Modell)
5. Höheres Migrationsrisiko bei gleichzeitigem Erhalt aller Edge-Cases

### Eignung für dieses Repo
- Gut für „finales“ Windows-11-Frontend
- Höheres initiales Risiko für ein kleines, hardware-nahes Tool mit Tray-Fokus

---

## Option 2: WPF mit modernem Fluent UI

### Vorteile
1. **Reif/stabil für Desktop + Tray-Szenarien**
2. Sehr gute Interop-Fähigkeit mit bestehender Windows-/COM-/Serial-Logik
3. Einfachere schrittweise Migration (ViewModel + Services)
4. Fluent-Look via Libraries (z. B. Wpf.Ui/ModernWpf/MahApps)
5. Geringeres Risiko bei Funktionsparität

### Risiken / Aufwand
- UI wird ebenfalls neu aufgebaut (XAML statt Designer)
- Tray typischerweise über `TaskbarIcon`-Library/WinForms-Interop
- Kein „WinUI-native“ Stack, obwohl visuell sehr nah an Windows 11 möglich

### Eignung für dieses Repo
- Sehr gut für **inkrementelle, risikoarme Modernisierung**
- Besonders passend wegen starkem Tray-/Hardware-/Interop-Fokus

---

## 11) Migrationrisiken (gesamt)

1. **Threading/Dispatching:** Serial + USB Events aktualisieren UI; bei neuer UI-Architektur sauber über Dispatcher marshallen.
2. **CoreAudio-Interop-Stabilität:** COM-Objekte korrekt freigeben, Session-Enumeration robust halten.
3. **Tray-Parität:** Show/Hide, Statusanzeigen, Exit-Verhalten exakt erhalten.
4. **Prozessname-Matching:** aktuelle Substring-Logik kann Fehlzuordnungen verursachen; bei Refactoring Verhalten testen.
5. **Konfigurationskompatibilität:** bestehende Settings-Werte migrieren ohne Datenverlust.
6. **Hardware-Protokoll-Kompatibilität:** `syn/ack/get/NR=*` unverändert beibehalten.
7. **Reconnect-Logik:** USB Disconnect/Connect muss weiterhin autonom funktionieren.

---

## 12) Empfohlene Zielarchitektur

**Empfehlung:**
- **Phase 1:** Architektur entkoppeln + WPF Fluent UI als neue Shell
- **Phase 2 (optional):** WinUI-3-Shell als zweite Frontend-Option auf derselben Core-Logik

### Zielprinzipien
- UI von Hardware-/Audio-Logik trennen
- Domain-Services testbar machen
- Protokoll und Business Rules unverändert halten

### Schichten
1. **Domain/Core**
   - Mix-Algorithmus
   - Kategorien (Game/Chat), Assignment-Modell
2. **Infrastructure**
   - `ISerialDeviceService`
   - `IAudioSessionService`
   - `IUsbWatcherService`
   - `ISettingsStore`
3. **Application Layer**
   - Orchestrierung, Commands, State Machine
4. **Presentation (WPF/WinUI)**
   - Views + ViewModels
   - Tray Adapter

---

## 13) Vorschlag Projektstruktur

```text
GameChatBalancer.sln
src/
  GameChatBalancer.Core/
	Models/
	Services/
	Rules/
  GameChatBalancer.Infrastructure.Windows/
	Audio/
	  CoreAudioInterop.cs
	  AudioSessionService.cs
	Serial/
	  SerialDeviceService.cs
	  ArduinoProtocol.cs
	Usb/
	  UsbWatcherService.cs
	Settings/
	  UserSettingsStore.cs
  GameChatBalancer.Application/
	UseCases/
	State/
	Contracts/
  GameChatBalancer.UI.Wpf/
	App.xaml
	Views/
	ViewModels/
	Tray/
  GameChatBalancer.UI.WinUI/   (optional, später)
	...
tests/
  GameChatBalancer.Core.Tests/
  GameChatBalancer.Application.Tests/
```

---

## 14) Inkrementeller Migrationsplan

## Phase 0 – Baseline absichern
1. Repro-Build + Laufzeit-Check dokumentieren
2. Protokollverhalten (`syn/ack/get/NR`) und Reconnect-Szenarien als Referenz festhalten
3. Kernflows als manuelle Test-Checkliste erfassen

## Phase 1 – Entkopplung im bestehenden Repo
1. Audio- und Serial-Logik in Services extrahieren (ohne Verhaltensänderung)
2. Settings-Zugriff kapseln
3. UI ruft nur noch Service-Interfaces auf

## Phase 2 – Neues WPF-Frontend (empfohlen)
1. Neues WPF-Projekt hinzufügen
2. ViewModels + Binding für:
   - App-Listen
   - Zuordnung Game/Chat
   - COM/NR/Invert
   - Status/Debug
3. Tray-Host implementieren (Show/Exit/Status)
4. Core-Services wiederverwenden

## Phase 3 – Paritätsvalidierung
1. Funktionale Vergleichstests WinForms vs WPF
2. Hardware Disconnect/Reconnect testen
3. Audio-Mix-Verhalten in Edge-Cases prüfen (50, Richtungswechsel, mehrere Prozesse)

## Phase 4 – Ablösung WinForms
1. WPF als primäres Deployable
2. WinForms nur noch Fallback (kurzfristig)
3. Nach Stabilitätsphase WinForms entfernen

## Phase 5 – Optionaler WinUI-3-Track
1. Auf derselben Core/Application-Schicht WinUI-UI prototypisieren
2. Tray/Lifecycle über Interop absichern
3. Nur übernehmen, wenn kein Funktionsverlust gegenüber WPF

---

## 15) Klare Empfehlung

Für dieses konkrete Repository ist **WPF + modernes Fluent UI** der beste erste Zielpfad:
- niedrigstes Risiko bei vollständigem Funktionserhalt
- beste Kontrolle über Tray-/Interop-/Hardware-Spezifika
- dennoch native Windows-11-Optik erreichbar

**WinUI 3** bleibt eine gute strategische Option als zweiter Schritt, sobald die Logik sauber entkoppelt ist.

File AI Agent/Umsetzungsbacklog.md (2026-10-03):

# GameChatBalancer – Umsetzungsbacklog (Tracking)

> Dieses Dokument ist das zentrale Steuerungsartefakt für die Migration.
> Es dient gleichzeitig als Arbeits-Backlog, Fortschritts-Tracker und gemeinsamer Referenzpunkt.

## Umgesetzte Leitlinien aus dem Master Prompt (relevant, neu)
- **Priorität strikt:** Funktionalität → Stabilität → Architektur → UX → Visual Design → Cleanup
- **Kleine Phasen statt Big-Bang-Rewrite** mit Quality-Gates je Phase
- **Keine Funktionsänderung ohne explizite Freigabe** (stattdessen dokumentieren)
- **Windows-11/Fluent-Zielbild** mit konsistentem Theme-System (Light/Dark/System)
- **Accessibility + DPI/Responsive** als feste Abnahmekriterien

## Quality-Gates (verbindlich je Phase)
1. Build ausführen (Solution/Projekt)
2. Fehler beheben
3. Warnings prüfen und auflösen (keine pauschale Suppression)
4. Regression gegen `AI Agent/Abnahmecheckliste-Ist-Verhalten.md`
5. Ergebnisse im Fortschrittsprotokoll dokumentieren

## Definition of Done (Modernisierung)
- [ ] Build erfolgreich
- [ ] App startet stabil
- [ ] System-Tray inkl. Show/Hide/Exit korrekt
- [ ] Game-/Chat-Balance unverändert funktionsfähig
- [ ] Arduino-Erkennung/COM/Reconnect/Invert funktionsfähig
- [ ] Settings speichern/laden ohne Verlust
- [ ] WPF-UI wirkt konsistent modern (Windows 11 / Fluent)
- [ ] Theme: Light/Dark/System funktioniert konsistent
- [ ] Drag & Drop für App-Zuordnung funktioniert
- [ ] DPI/Scaling ok (125%/150%)
- [ ] Fenstergrößen ok (1280x720, 1920x1080, 2560x1440)
- [ ] Accessibility-Basis erfüllt (Keyboard/Focus/Kontrast/Tooltips)
- [ ] Keine unnötigen Dependencies hinzugefügt

## Status-Legende
- `☐` Offen
- `◐` In Arbeit
- `☑` Erledigt
- `⚠` Blockiert

## Prioritäts-Legende
- `P0` Kritisch / zuerst
- `P1` Hoch
- `P2` Mittel
- `P3` Niedrig

## Meilensteine
- **M1:** Baseline + .NET-Upgrade abgeschlossen
- **M2:** Architektur entkoppelt (Core/Application/Infrastructure)
- **M3:** WPF-UI funktionsgleich zur WinForms-App
- **M4:** Produktionsreife inkl. Stabilisierung
- **M5 (optional):** WinUI-3-Track bewertet/prototypisiert

## Leitplanke (Entscheidung)
- **Primärer Migrationspfad:** WPF mit Fluent UI
- **WinUI 3:** nur optionaler Folgepfad in späterer Projektphase

---

## EPIC 00 – Projektsteuerung & Qualität

| ID | Status | Prio | Aufgabe | Abhängigkeit | Ziel/Definition of Done |
|---|---|---:|---|---|---|
| 00.01 | ☑ | P0 | Test-/Abnahmecheckliste aus Ist-Verhalten erstellen | - | Checkliste deckt: Tray, COM-Auto, USB-Reconnect, NR, Assignments, Persistenz |
| 00.02 | ☐ | P0 | Logging/Diagnose-Standard definieren | 00.01 | Fehlerpfade für Serial, Audio, USB sind nachvollziehbar |
| 00.03 | ☐ | P1 | Release- und Rollback-Strategie dokumentieren | 00.01 | Klarer Fallback auf letzte stabile Version |
| 00.04 | ☐ | P1 | Potential-Improvement-Log einführen (ohne sofortige Umsetzung) | 00.01 | Verbesserungen nur dokumentiert, keine stillen Funktionsänderungen |

---

## EPIC 01 – Frühe Plattform-Migration auf aktuelles .NET

> **Vorgabe:** .NET-Migration in einer frühen Projektphase umsetzen.

| ID | Status | Prio | Aufgabe | Abhängigkeit | Ziel/Definition of Done |
|---|---|---:|---|---|---|
| 01.01 | ☑ | P0 | Zielversion festlegen (aktuelles LTS) | - | Ziel-TFM entschieden und dokumentiert |
| 01.02 | ☑ | P0 | Projekt auf neues .NET-TFM migrieren | 01.01 | Build erfolgreich auf neuem TFM |
| 01.03 | ☑ | P0 | Paketkompatibilität prüfen/aktualisieren | 01.02 | `System.IO.Ports`, `System.Management` kompatibel |
| 01.04 | ☑ | P0 | Smoke-Test Kernfunktionen auf neuem TFM | 01.02, 01.03 | Tray, Serial, Audio, Persistenz laufen unverändert |
| 01.05 | ☑ | P1 | CI/Build-Konfiguration auf neues .NET aktualisieren | 01.02 | Reproduzierbarer Build lokal + CI |

## EPIC 02 – Architektur-Entkopplung (ohne UI-Wechsel)

| ID | Status | Prio | Aufgabe | Abhängigkeit | Ziel/Definition of Done |
|---|---|---:|---|---|---|
| 02.01 | ☐ | P0 | Domain-Modelle und Mix-Regel isolieren | 01.04 | Mix-Berechnung als testbare Kernlogik |
| 02.02 | ☑ | P0 | `IAudioSessionService` + Implementierung kapseln | 02.01 | Audio-Interop nur noch über Interface |
| 02.03 | ☑ | P0 | `ISerialDeviceService` + Protokolladapter kapseln | 02.01 | `syn/ack/get/NR` in separater Service-Schicht |
| 02.04 | ☑ | P0 | `IUsbWatcherService` kapseln | 02.03 | Reconnect-Events UI-unabhängig |
| 02.05 | ☑ | P0 | `ISettingsStore` einführen | 02.01 | Persistenzzugriffe zentralisiert |
| 02.06 | ☑ | P1 | WinForms nur als Adapter auf neue Services | 02.02-02.05 | Bestehende UI funktional unverändert, aber entkoppelt |

## Aktueller Fokus (Startvorschlag)
1. `03.01` WPF-Projektgrundstruktur
2. `03.02` WPF ViewModels für Assignment/Hardware/Status
3. `03.04` WPF Tray-Integration
4. `03.05` WPF Hardware-Steuerung anbinden
5. `03.03` WPF Drag&Drop-Zuordnung
6. `03.06` Systray-/Lifecycle-Host von `Form1` entkoppeln (eigenen Host einführen), danach `Form1` vollständig entfernen

## Nächste Umsetzungssequenz (ab jetzt)
1. `04.01` Windows-Autostart als Option umsetzen (Registry HKCU Run + WPF Toggle + Persistenz)
2. `04.02` Systray-Bereich an neues Design anpassen (ohne Lifecycle-Bruch)
3. `04.03` `Form1` schrittweise entkoppeln und entfernen (Host kapseln, dann UI-Adapter abbauen)

### Phase 04.01 – Autostart (Detailplan)
- `04.01.01` `IAutoStartService` Vertrag definieren
- `04.01.02` `AutoStartService` implementieren (lesen/setzen/entfernen in `HKCU\\Software\\Microsoft\\Windows\\CurrentVersion\\Run`)
- `04.01.03` `ISettingsStore`/`SettingsStore` um `StartWithWindows` ergänzen
- `04.01.04` Form1-Integration als WPF-Callback verdrahten
- `04.01.05` WPF-Toggle „Start with Windows“ anbinden und initialisieren
- `04.01.06` Fehlerpfad + Debug-Logging ergänzen
- `04.01.07` Build + manueller Registry-Funktionstest

## Fortschrittsprotokoll

| Datum | Änderung | Verantwortlich |
|---|---|---|
| 2026-09-29 | 04.01 umgesetzt: Windows-Autostart-Option integriert (`IAutoStartService`/`AutoStartService`, WPF-Toggle „Start with Windows“, OS↔Settings-Sync, Fehler-Rollback + Debug-Logging); Build + Registry-Smoketest erfolgreich | AI Agent |
| 2026-09-29 | Roadmap erweitert: Sequenz 04.01 Autostart, 04.02 Systray-Modernisierung, 04.03 Form1-Entkopplung/Entfernung priorisiert; Detailplan für 04.01 ergänzt | User + AI Agent |
| 2026-09-27 | 03.03 korrigiert: AudioSessionsChanged auf robustes CoreAudio-Session-Monitoring umgestellt (dedizierter MTA-Thread + sauberes Register/Unregister), damit SessionCreated-Events zuverlässig ankommen; Build erfolgreich | AI Agent |
| 2026-09-27 | 03.03 fortgeführt: Eventbasierte Auto-Aktualisierung für neu erscheinende Audio-Sessions ergänzt (CoreAudio `SessionCreated` statt Prozessstart-Trigger), inkl. sauberem Start/Stop/Unsubscribe für rückbaubare Änderung; Build erfolgreich | AI Agent |
| 2026-09-27 | Planung ergänzt: neuer Schritt `03.06` aufgenommen, um Systray/Lifecycle aus `Form1` zu lösen und `Form1` später löschen zu können | User + AI Agent |
| 2026-09-27 | 03.03 begonnen: WPF Assignment-Listen auf echte Daten umgestellt (Game/Chat/Verfügbar inkl. App-Icons), Drag&Drop zwischen Kategorien implementiert, Persistierung der Zuordnung zeitnah über `ISettingsStore.ScheduleSave()` verdrahtet, Build erfolgreich | AI Agent |
| 2026-09-27 | 03.05 fortgeführt: Hardware-Status modernisiert (Status-Dot, Noise Reduction, Invert-Toggle inkl. Arduino-Confirm/Apply/Error-Visualisierung), COM-Port-UI bewusst entfernt bei unveränderter Service-Logik, Build erfolgreich | AI Agent |
| 2026-09-27 | 03.02 fortgeführt: Assignment-Bereich auf 2-Ebenen-Layout umgestellt (oben Game/Chat, darunter volle Breite „Verfügbare Apps (nicht zugewiesen)“), Build erfolgreich | AI Agent |
| 2026-09-27 | 03.02 gestartet: WPF Basis-Shell + Sidebar-Navigation umgesetzt (`GameChatBalancer.Wpf`), Design-Token/Theme-Ressourcen in `App.xaml` angelegt, Build erfolgreich | AI Agent |
| 2026-09-27 | 03.01 abgeschlossen: WPF-Projekt `GameChatBalancer.Wpf` erstellt und in `AudioControl.sln` eingebunden, Ziel-TFM `net10.0-windows` verifiziert, Build erfolgreich | AI Agent |
| 2026-09-26 | 01.05 abgeschlossen: CI-Workflow hinzugefügt (`.github/workflows/ci.yml` mit Restore/Build/Test auf .NET 10), SDK-Pinning via `global.json` (`10.0.401`), lokale Validierung per Build/Test erfolgreich | AI Agent |
| 2026-09-26 | Adapter-Bereinigung nachgezogen: verbleibende direkte `USBandCOM`/`Properties.Settings`-Zugriffe in `Form1` (COM-Port-Handler) entfernt; Reconnect-Overhead reduziert (Reconnect-Guard + keine Deletion-Reconnects ohne aktive Verbindung), Build erfolgreich | AI Agent |
| 2026-09-26 | 02.06 abgeschlossen: `Form1` weiter als UI-Adapter geschnitten (Audio-Mix in `IAudioBalanceService`, verbleibende direkte `USBandCOM`/Settings-Zugriffe entfernt), Build erfolgreich | AI Agent |
| 2026-09-26 | 02.05 abgeschlossen: `ISettingsStore` + `SettingsStore` eingeführt, `Form1` auf Settings-Service umgestellt, hybride Persistenz (deferred + immediate) implementiert, SessionEnding-Fallback für Windows-Shutdown ergänzt, Build erfolgreich | AI Agent |
| 2026-09-26 | 02.02 abgeschlossen: `IAudioSessionService` + `AudioSessionService` eingeführt, `Form1` nutzt Audio-Service statt direkter `AudioManager`-Aufrufe, Build erfolgreich | AI Agent |
| 2026-09-26 | 02.04 abgeschlossen: `IUsbWatcherService` + `UsbWatcherService` eingeführt, USB-Watcher Start/Stop in `Form1` entkoppelt, Build erfolgreich | AI Agent |
| 2026-09-26 | 02.03 abgeschlossen: `ISerialDeviceService` + `SerialDeviceService` eingeführt, `Form1` nutzt Serial-Service statt direkter `USBandCOM`-Aufrufe | AI Agent |
| 2026-09-26 | 01.04 abgeschlossen: Retest nach Shutdown-Fix erfolgreich (inkl. Debug-Stop ohne Fehler), Build weiterhin erfolgreich | User + AI Agent |
| 2026-09-26 | 01.04 gestartet: Smoke-Test-Dokument angelegt (`AI Agent/Smoke-Test-01.04-net10.md`), Build-Teil bestanden, manuelle Hardware-/UI-Validierung ausstehend | AI Agent |
| 2026-09-26 | Plan um Master-Prompt-Leitlinien ergänzt (Quality-Gates, DoD, Accessibility, Responsive/DPI, Potential-Improvement-Log) | User + AI Agent |
| 2026-09-25 | 01.03 abgeschlossen: `System.IO.Ports` und `System.Management` auf `10.0.12` aktualisiert, Build erfolgreich | AI Agent |
| 2026-09-25 | 01.02 abgeschlossen: TFM auf `net10.0-windows` angehoben, Build erfolgreich; WinForms-Warnungen (WFO1000) in `Form1` behoben | AI Agent |
| 2026-09-25 | 01.01 abgeschlossen: Zielversion auf `net10.0-windows` festgelegt | User + AI Agent |
| 2026-09-25 | 00.01 abgeschlossen: Abnahmecheckliste erstellt (`AI Agent/Abnahmecheckliste-Ist-Verhalten.md`) | AI Agent |
| 2026-09-25 | Konkreter Startplan ergänzt: .NET zuerst, danach Entkopplung von USBandCOM/AudioManager | User + AI Agent |
| 2026-09-25 | UI-Strategie konkretisiert: WPF als Primärpfad akzeptiert, WinUI 3 auf später verschoben | User + AI Agent |
| YYYY-MM-DD | Backlog initial erstellt | AI Agent |

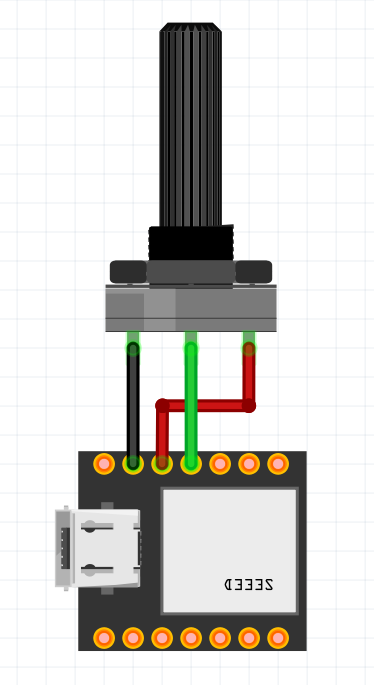
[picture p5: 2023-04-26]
assets/GameChatBalancer_schematic.png

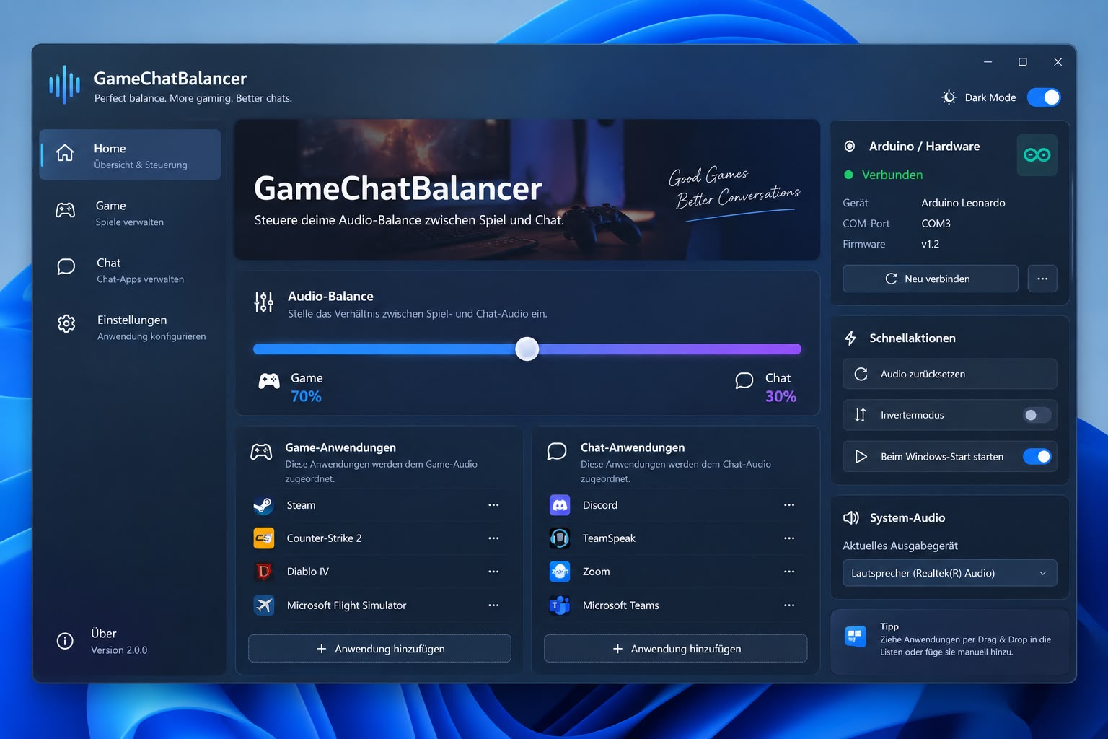
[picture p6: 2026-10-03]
assets/design-reference/GameChatBalancer-Reference.jpeg

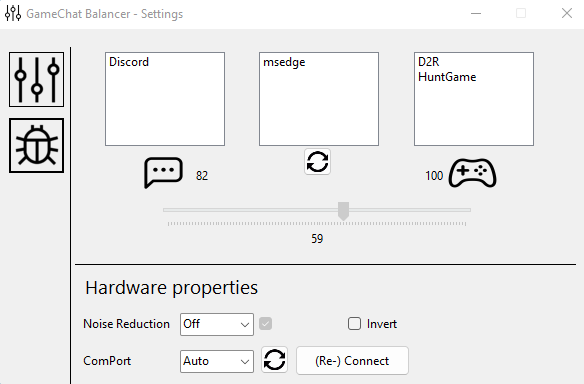
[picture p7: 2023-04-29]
assets/GCB_settings.png

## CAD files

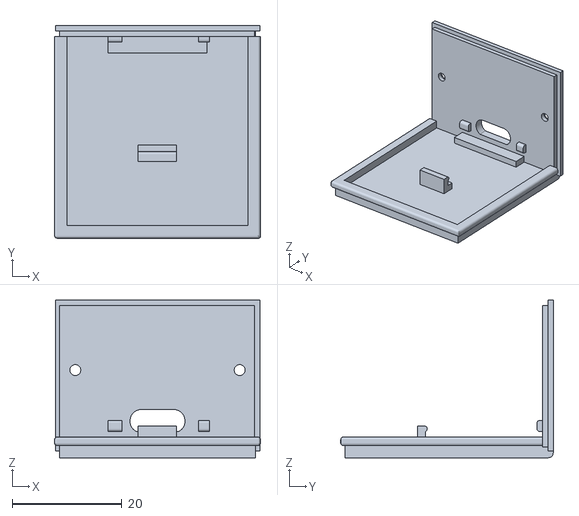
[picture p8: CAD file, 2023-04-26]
assets/3d-model/GCB_Back.stl
37.6 x 38.8 x 28.8

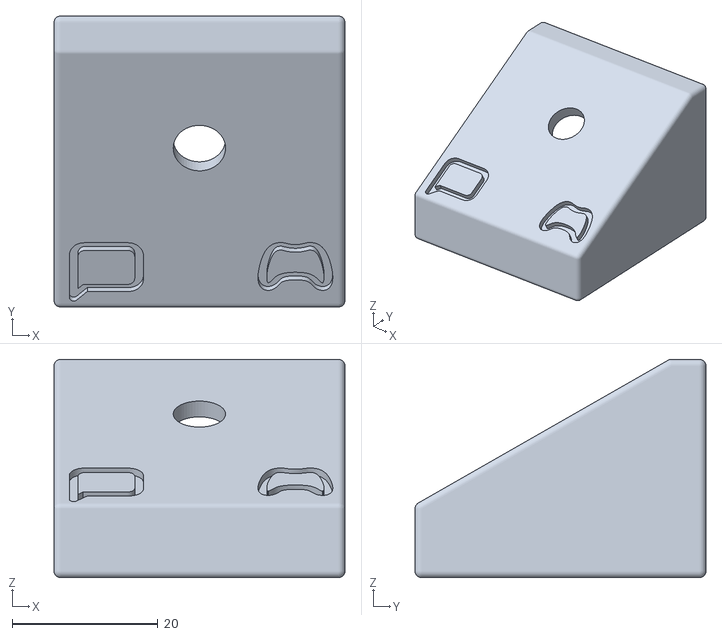
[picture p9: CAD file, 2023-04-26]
assets/3d-model/GCB_Body.stl
40.0 x 40.0 x 30.0

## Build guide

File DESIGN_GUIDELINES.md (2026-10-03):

# Design Guidelines

## Language
- The entire application UI language must be English.
- All labels, buttons, tooltips, section titles, status texts, and validation/error messages must be written in English.
- Do not mix English and German in the UI.

## Units and Formatting
- Use seconds for overlay display duration.
- Display duration values in the UI as `s` (for example: `3 s`).
- Do not use milliseconds (`ms`) for overlay duration in the UI.

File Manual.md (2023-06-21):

# GameChatBalancer - Build

## What you need
You need the following things to bould your own GameChatBalancer:

- 1 Arduino or compatible microcontroller. I recommend a **Seeed Xiao SAMD21 Cortex M0+**
- 1 Linear potentiometer with a low tolarance for the best result. I used a **Alpha RV16AF20KB10KM** (tolerance: +-5%) 
- 1 Knob, which will be set on top of the potentiometer
- 20-30 cm isolated copper wire
- 1 USB cable matching the connection of your microcontroller of choice. The Seeed board has a USB-C connector.
- soldering iron to connect the potentiometer to your microcontroller
- some kind of housing for the microcontroller and the potentiometer

Have a look at the [Readme.md](https://github.com/TheSoundCoder/GameChatBalancer/blob/master/README.md#material) to get an cost overview and links to products.

## How to connect
- The potentiometer is connected to an **analog pin (A\*)** of your Arduino (or compatible) board. It is powered from the board's 5V (or 3.3V for a Seeed board) output (see schematic)
  - GND = black
  - 5V / 3.3V = red
  - Signal = green
- The board is conected via an USB cable to the PC.

### Schematic
In the schematic below, you find two options:
1. Left is the setup with the Seeed Xiao SAMD21 Cortex M0+. **Ensure to connect the potentiometer to the 3.3V output** of the board as the 5V will probably kill the board's microcontroller.
2. Right is the setup with an Arduino.



If you connect everything exactly as shown in the schematic, the potentiometer will be connected to the **A0 pin** of your microcontroller. If you used another Analog pin, you need to change the sketch before uploading it to your board. See [below](https://github.com/TheSoundCoder/GameChatBalancer/blob/master/Manual.md#changeanaloguepin)

# GameChatBalancer - Installation

## Arduino
**Prerequisite**: You should have the **Arduino IDE** installed on your PC. You can download it [here](https://www.arduino.cc/en/software).
- Download the file **GCBalancer.ino** from the latest release of this project (you should find it at the right side under "Releases").
- Open the downloaded sketch GCBalancer.ino with the installed Arduino IDE
- Follow the instructions "How to upload a sketch with the Arduino IDE 2" from the [Arduino website] (https://docs.arduino.cc/software/ide-v2/tutorials/getting-started/ide-v2-uploading-a-sketch)

### Change analog pin
You can change the used analog pin in **line 1** of the sketch. Change the value to whatever the **output pin** of your potentiometer (green line in the shematic above) is connected to.

Sketch

### Test
After uploading the sketch, open the serial monitor of thr Arduino IDE by choosing *Tools* ->  *Serial Monitor* (or by pressing `strg` + `shift` + `M`).

If you turn the potentiometer (or move the slider) you should see **values between 0 and 100** coming in. If this is true: Congratulations! Your device is working as it should.

**Close the serial monitor.** Keeping it open might prevent you from uploading a sketch in the future.

## Systray application
- Download the file **GCBalancer_win.zip** from the latest release of this project (you should find it at the right side under "Releases").
- Store the content of the ZIP file in any folder of your choice.
- Run **GCBalancer.exe** from the folder above.
- **Optional**: Add GCBalancer.exe to **Autostart** if you want to run it at system startup.
  - Press `Win` + `R` to open the Run menu
  - Type shell:startup and press enter
  - Right click and create a new link to GCBalancer.exe

# Manual - Systray application
The application will start in the systray:



A right click will open the context menu. The first row shows the **connection status** (COM4) to your DIY hardware device. The second row shows the **last recieved value** (59) from the hardware.

Clicking on **Show** will open the GUI so that you can configure GameChatBalancer:

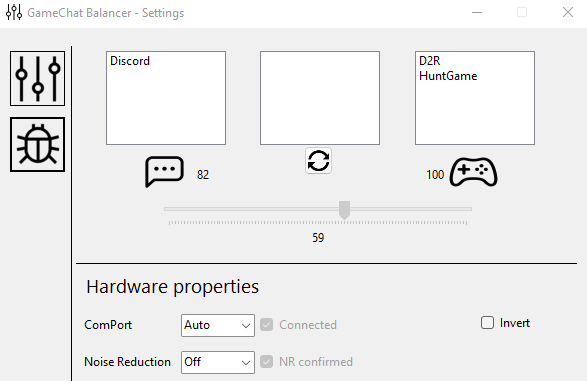
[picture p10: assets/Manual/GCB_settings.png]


The two symbols on the left ("Equalizer" and "Bug") let you switch between the [Settings](https://github.com/TheSoundCoder/GameChatBalancer/blob/master/Manual.md#settings) and [Debug](https://github.com/TheSoundCoder/GameChatBalancer/blob/master/Manual.md#debug) area.

## Settings
The settings area is your **command center** for this application. It has two main areas:
- Hardware properties
- Audio settings

We will start with the hardware properties as this might be of interest on the first startup.

### Hardware properties
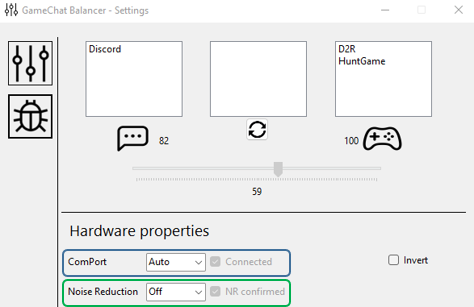
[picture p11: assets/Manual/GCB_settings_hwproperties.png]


#### ComPort (blue)
In the Hardware properties area, you can choose the **COM port** for your DIY hardware. Usually it should be a COM port greater than COM2. **I recomment to leave this setting to "Auto"**. In this case GameChatBalancer will **auto-detect your DIY hardware by doing a basic handshake** (syn <> ack).

If your device is properly connected the checkbox "Connected" will be checked. Otherwise in a disconnected state this checkbox will be unchecked. 

#### Noise reduction (green)
Here you can set the Noise reduction level for your Arduino. Changing this setting will be confirmed by the hardware. In this case the Checkbox "NR confirmed" will be checked.

As cheap potentiometers / sliders can cause noise, it is important to modify this setting to the quality of used components. 

*What is noise?* - The Arduino / Seeed XIAO microcontroller reads the analog resistor value of your potentiometer, resulting in values between 0 and 1023. If you do not touch your potentiometer, this value should be static. If you turn your potentiometer to the middle position, this value should be ~512. A cheap potentiometer has a higher tolerance, meaning that this value will not be static, but will vary for example between 508 and 516.

*Why is noise bad?* - To **reduce the traffic on the Com port and to reduce the CPU load of your PC**, the Arduino sketch is implemented to only send a value to the PC, if it deviates from the previously sent value.
No turn on the potentiometer -> No change in values -> No data is sent to the PC -> GameChantBalancer Systray application keeps sleeping.
Noise will cause a constant stream of new values between the Arduino and your PC and might cause an increased CPU load as the volume settings for applications are constantly modified.

*Which level of noise reduction should I use?* - If you want to validate if the chosen noise reduction level matches the quality of your potentiometer, use the  [Debug](https://github.com/TheSoundCoder/GameChatBalancer/blob/master/Manual.md#debug) area as follows.
1. Enable debugging
2. Start with *Noise reduction* set to *off*.
3. Wait until the microcontroller confirms the chosen debug level. (Checkbox "NR confirmed" (Settings - Hardware properties) is checked.)
4. Change to the Debug area
5. **Do not turn the potentiometer or move the slider**
6. If the debug window shows a lot of altering values coming in, change to a higher noise reduction level.
7. Return with #3, except you already reached the noise reduction level "High". ;-)

*What is the downside of noise reduction?* - If noise reduction is set to medium or high, the application will "drop" 1 value at level medium und 2 values at level high **if you change the direction when turning the potentiometer**. The reason is that those values are buffered and not sent by the microcontroller. At level high it will look as follows (example):
- Initial value 50
- Turn the potentiometer left until you reach 45
- Start turing the potentiometer right. The first value will be **48 instead of 46** as 45, 46 and 47 are in the local buffer for noise reduction.

### Audio settings
The audio settings are located above the Hardware properties.

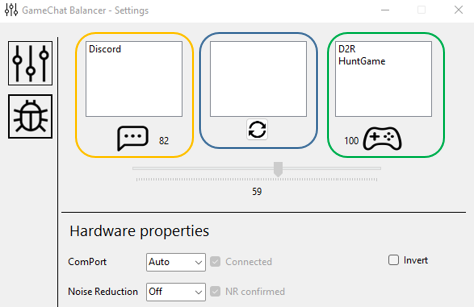
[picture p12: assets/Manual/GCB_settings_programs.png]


You can assign applications to the **chat** (yellow) or **game** (green) category by **dragging and dropping** them from the list of **available programs** (blue). ([see Video](https://github.com/TheSoundCoder/GameChatBalancer/edit/master/README.md#pictures--video))

If a program you want to assign is not listed in the blue area:
- **start the program** 
- press the **refresh icon** below the listbox - your program should appear now
- assign the program via drag & drop

If you mixed up the ground and power wires during the built, you can invert the behaviour of the potentiometer by checking the **"Invert" checkbox** in the Hardware properties.

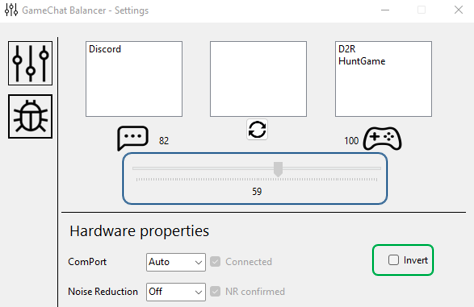
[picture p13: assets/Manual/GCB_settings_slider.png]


## Debug
You can see debug messages in the debug area of the application. To enable debug messages just activate the highlighted checkbox.

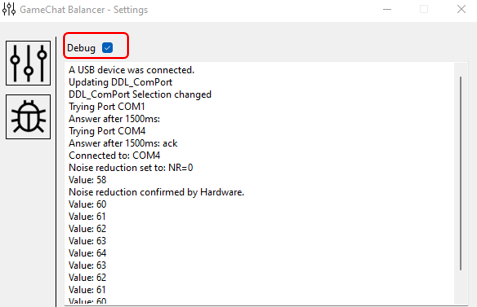
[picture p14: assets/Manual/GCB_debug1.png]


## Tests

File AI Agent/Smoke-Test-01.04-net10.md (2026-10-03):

# Smoke-Test 01.04 – net10.0-windows

## Kontext
- Ziel: Kernfunktionen nach TFM-/Paketmigration verifizieren
- Build-Stand: erfolgreich auf `net10.0-windows`
- Pakete: `System.IO.Ports` = `10.0.12`, `System.Management` = `10.0.12`

## Automatisiert geprüft
- [x] Projekt-Build erfolgreich (`AudioControl.csproj`)
- [x] Keine Build-Fehler

## Manuell zu prüfen (Hardware-/UI-abhängig)
Referenz: `AI Agent/Abnahmecheckliste-Ist-Verhalten.md`

### A. Start- und Tray-Verhalten
- [ ] A1 Start im Tray
- [ ] A2 Tray-Menü/Status
- [ ] A3 Show/Hide/Exit

### B. COM-Port & Auto-Detect
- [ ] B1 COM-Portliste
- [ ] B2 Auto-Detect + Handshake (`syn/ack`)
- [ ] B3 Manuelle COM-Auswahl + Reconnect

### C. USB-Reconnect
- [ ] C1 USB trennen
- [ ] C2 USB wieder verbinden

### D. Hardware-Protokoll / Noise Reduction
- [ ] D1 Initialwertabruf (`get`)
- [ ] D2 NR setzen/Bestätigung (`NR=0..3`)

### E. Audio-Session-Erkennung & Assignment
- [ ] E1 Prozessliste + Refresh
- [ ] E2 Drag & Drop Assignment

### F. Mix-Logik
- [ ] F1 <50 / =50 / >50 Verhalten
- [ ] F2 Invert-Verhalten

### G. Persistenz
- [ ] G1 Speichern
- [ ] G2 Wiederherstellung nach Neustart

### H. Debug (optional)
- [ ] H1 Debug-Ausgaben

## Ergebnisstatus
- **Automatisierter Teil:** bestanden
- **Gesamtstatus 01.04:** offen bis manuelle Validierung abgeschlossen ist

## Hinweis
Für Abschluss von 01.04 werden manuelle Tests am Zielsystem mit angeschlossener Hardware benötigt.

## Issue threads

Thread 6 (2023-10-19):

Bluetooth?

DrewBrummett, 2023-10-19:
Hello! I've looked for so long for this exact thing and I was so excited to find it! I can't wait to try to build it. I'm curious though if it's possible to include a Bluetooth component allowing the use of Bluetooth headphones?

TheSoundCoder, 2023-10-20:
GameChatBalancer should work with all kind of audio devices connected to your Windows PC (wired and wireless) as it uses the Windows mixer to control the volume of the different applications.

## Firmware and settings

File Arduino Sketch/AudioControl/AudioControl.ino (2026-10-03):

int analogPin = A0; // potentiometer wiper (middle terminal) connected to analog pin 0

int val1 = 0;       // current potentiometer value (0-100)
int val1_old = 0;  // previous value
String incomingMsg = "";

// Noise Reduction:
// 0 = disabled (1 sample)
// 1 = Low    (16 samples)
// 2 = Medium (32 samples)
// 3 = High   (64 samples)
//
// DO NOT CHANGE.
// This can be modified using the Systray application.
int intNRLevel = 3;
int samples = 64;

void setup() {
  // put your setup code here, to run once:
  Serial.begin(115200);
  analogReadResolution(10);
}

void loop() {
  // Read potentiometer using the configured amount of samples
  val1 = readPotentiometer();
  // Convert ADC value (0-1023) to balancing value (0-100)
  val1 = map(val1, 0, 1023, -2, 202);
  // Only send value if it has changed
  if (abs(val1 - val1_old) >=2) {
    val1_old = val1;
    if (val1>200){val1=200;}  //only send values <= 100
    if (val1<0){val1=0;} //do not send negative values
    Serial.println(val1/2);
  }
  // Check for incoming serial commands
  Incoming();
}

/*
 * Reads the potentiometer multiple times and returns
 * the average ADC value.
 */
int readPotentiometer() {
  long sum = 0;
  for (int i = 0; i < samples; i++) {
    sum += analogRead(analogPin);
  }
  return sum / samples;
}

int setSample(){
/*
 * Noise Reduction levels:
 * 0 = 1 sample
 * 1 = 16 samples
 * 2 = 32 samples
 * 3 = 64 samples
 */
  switch (intNRLevel) {
    case 1:
      samples = 16;
      break;
    case 2:
      samples = 32;
      break;
    case 3:
      samples = 64;
      break;
    case 0:
    default:
      samples = 1;
      break;
  }
}

/*
 * Handle incoming serial commands.
 */
void Incoming() {
  if (Serial.available() > 0) {
    incomingMsg = Serial.readString();
    // Used to autodetect the device
    if (incomingMsg.indexOf("syn") > -1) {
      Serial.println("ack");
    }
    // Send current value on request
    if (incomingMsg.indexOf("get") > -1) {
      Serial.println(val1);
    }
    // Set and acknowledge Noise Reduction level
    if (incomingMsg.indexOf("NR=") > -1) {
      int newNRLevel = incomingMsg.substring(3, 4).toInt();
      // Only accept valid Noise Reduction levels
      if (newNRLevel >= 0 && newNRLevel <= 3) {
        intNRLevel = newNRLevel;
        setSample();
      }
      Serial.println("NR=" + String(intNRLevel));
    }
  }
}

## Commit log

2023-04-15 .gitattributes und .gitignore hinzufügen.
2023-04-25 Add files via upload
    Adjustable noise reduction implemented
    [AudioControl.ino]
2023-06-21 Application crash fixed when no audio device is connected
2023-06-21 Fixed application crash when no audio device exists at startup
2026-10-03 Enhance potentiometer reading and noise reduction
    Refactor potentiometer reading and noise reduction logic. Implement averaging for potentiometer values and improve serial command handling.
    [AudioControl.ino]
